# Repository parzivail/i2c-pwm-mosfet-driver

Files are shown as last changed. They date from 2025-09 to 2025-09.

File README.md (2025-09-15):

# I2C PWM MOSFET Driver

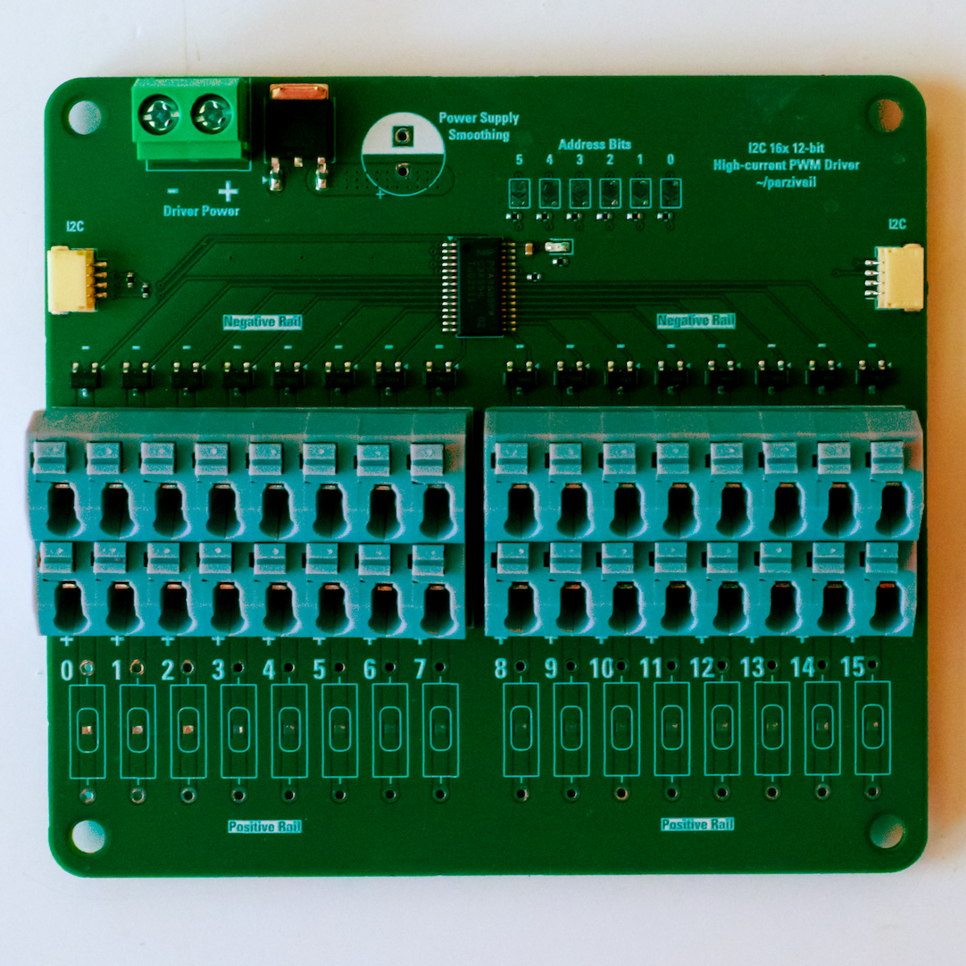
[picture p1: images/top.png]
An image of the circuit board


Buy this board [on Tindie](www.tindie.com/products/parzivail/i2c-pwm-mosfet-driver-mk-1/)!

This PWM driver board uses a PCA9685 controlled over I2C to drive up to 16 high-current loads with PWM via N-channeo MOSFETs. Perfect for 12V or 24V LED strips.

- PCA9685 PWM controller with 12-bit PWM resolution
- 3.3V and 5V compliant VCC and I2C
- Terminal block for driver power, isolated from chip power (provided over I2C)
- 16 independently-controlled outputs with up to 30V 3A per channel, driven by AO3400A N-channel MOSFETs
- Supports up to 5A total across all channels
- Reverse polarity protection via HXY AOD413A P-channel MOSFET up to 8A at 10V
- Two STEMMA QT/QUIIC-compatible I2C headers for daisy chaining
- 6-bit address select broken out on solder pads
- Spring-loaded terminal blocks for driver output
- Pads on each channel for optional current limiting resistors (bypassed by default with a solder jumper)
- Pads for optional power supply smoothing capacitor
- Red power LED
- 10K Pull-ups to VCC on SDA and SCL
- Compatible with Adafruit's PCA9685 libraries for Arduino and CircuitPython

## Changes from Mk1 to Mk2

- Removed polarity protection P-channel MOSFET
- Increased trace widths on each channel
- Converted an entire internal layer to a +V_LED power path

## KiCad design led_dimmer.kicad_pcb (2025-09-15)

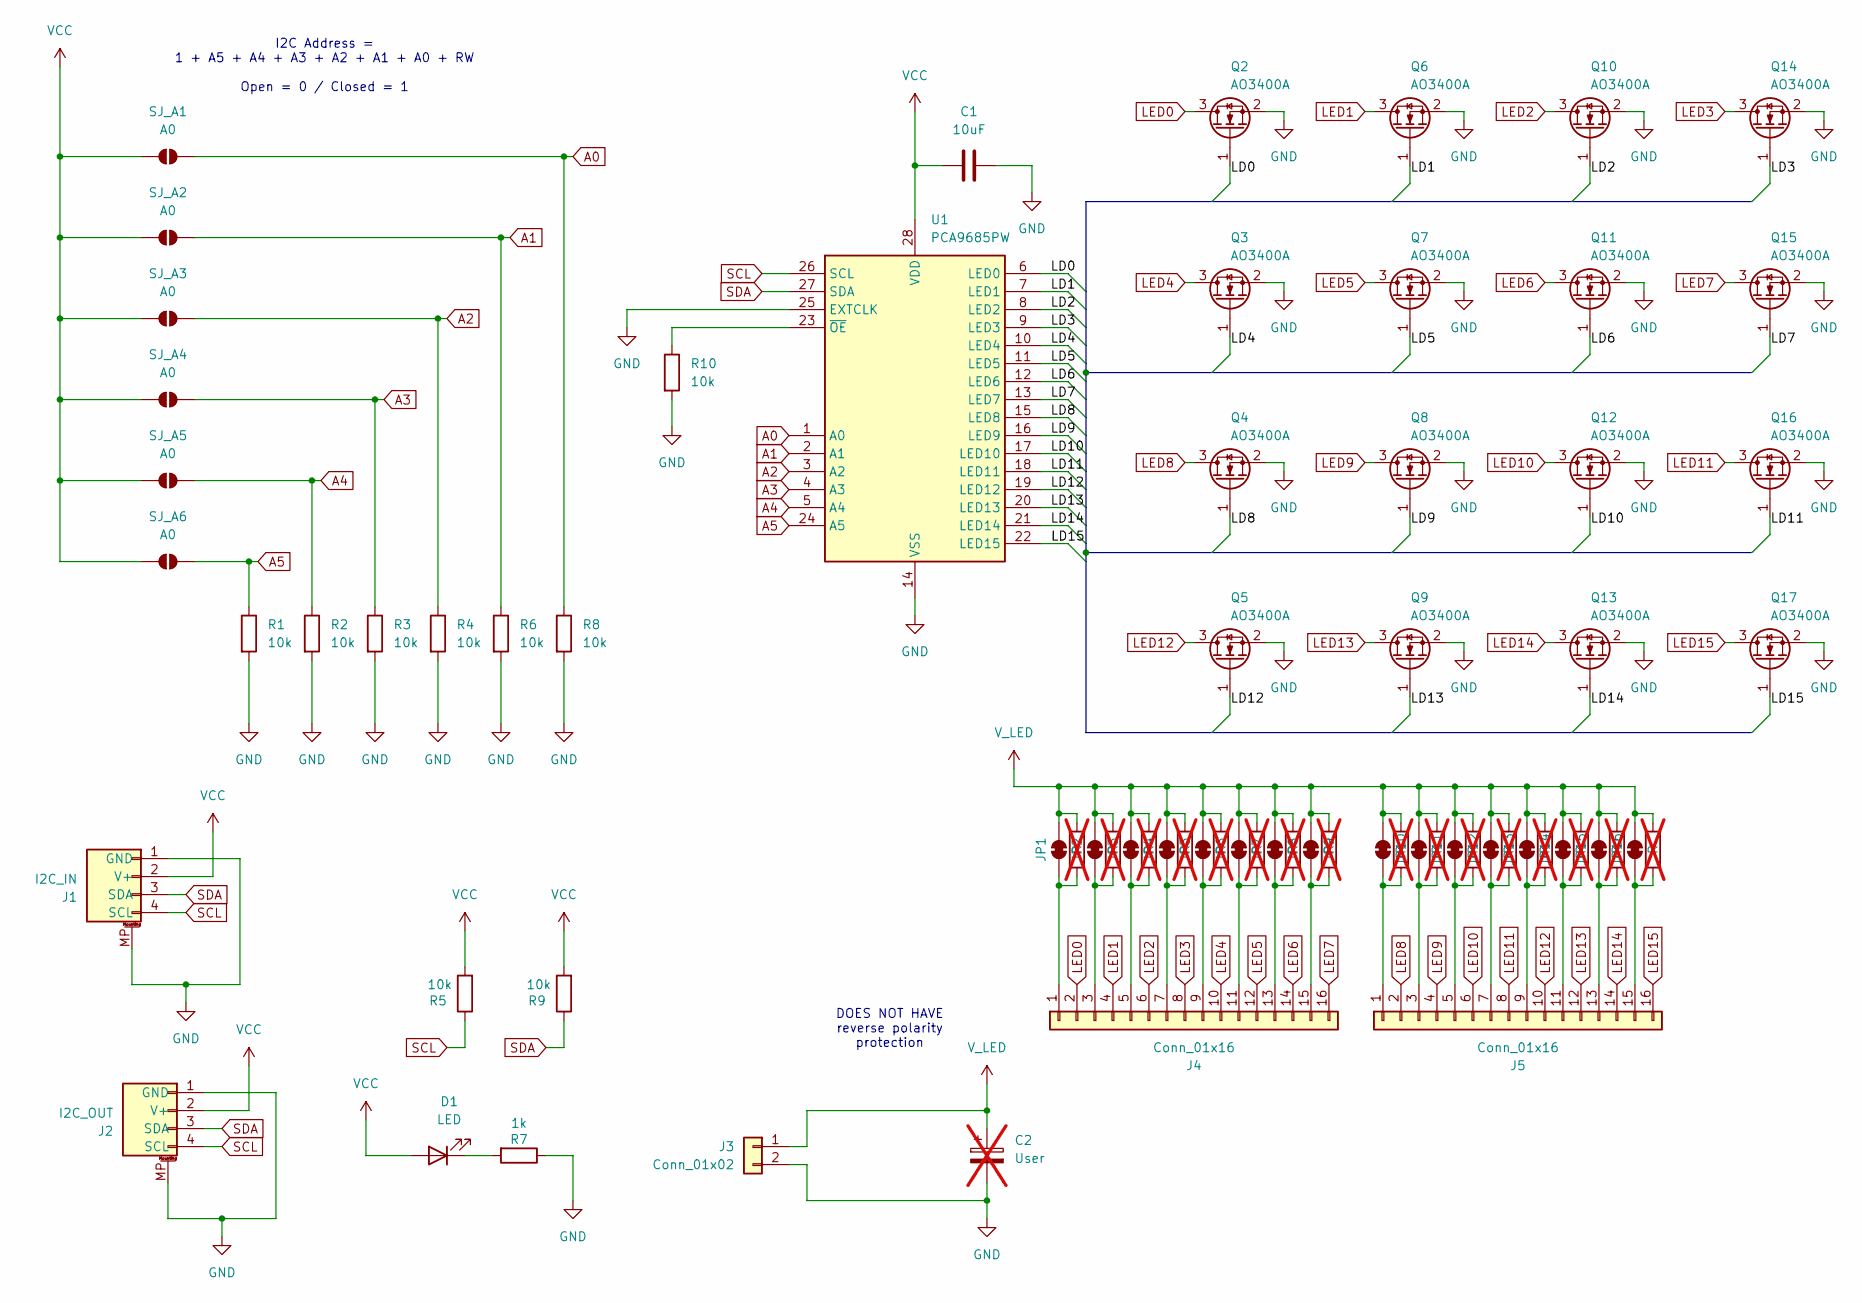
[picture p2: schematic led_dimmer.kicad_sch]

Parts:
C1: 10uF; C_0402_1005Metric; LCSC Part C15525
C2: User; CP_Radial_D8.0mm_P3.50mm; not fitted
D1: LED; LED_0603_1608Metric; LCSC Part C2286
J1: I2C_IN; JST_SH_SM04B-SRSS-TB_1x04-1MP_P1.00mm_Horizontal; LCSC Part C160404
J2: I2C_OUT; JST_SH_SM04B-SRSS-TB_1x04-1MP_P1.00mm_Horizontal; LCSC Part C160404
J3: Conn_01x02; TerminalBlock_Phoenix_MKDS-1,5-2_1x02_P5.00mm_Horizontal; LCSC Part C8404
J4, J5: Conn_01x16; CONN-TH_KF250T-5.0-2X8P; LCSC Part C976542
JP1, JP2, JP3, JP4, JP5, JP6, JP7, JP8, JP9, JP10, JP11, JP12, JP13, JP14, JP15, JP16: SolderJumper_2_Bridged; HighCurrentJumper
Q2, Q3, Q4, Q5, Q6, Q7, Q8, Q9, Q10, Q11, Q12, Q13, Q14, Q15, Q16, Q17: AO3400A; SOT-23; LCSC Part C20917
R1, R2, R3, R4, R5, R6, R8, R9, R10: 10k; R_0402_1005Metric; LCSC Part C25744
R7: 1k; R_0402_1005Metric; LCSC Part C11702
R11, R12, R13, R14, R15, R16, R17, R18, R19, R20, R21, R22, R23, R24, R25, R26: R; R_Axial_DIN0309_L9.0mm_D3.2mm_P12.70mm_Horizontal; not fitted
SJ_A1, SJ_A2, SJ_A3, SJ_A4, SJ_A5, SJ_A6: A0; SolderJumper-2_P1.3mm_Open_TrianglePad1.0x1.5mm
U1: PCA9685PW; TSSOP-28_4.4x9.7mm_P0.65mm; LCSC Part C2678753

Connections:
/LD0: Q2.1 (G), U1.6 (LED0)
/LD1: Q6.1 (G), U1.7 (LED1)
/LD2: Q10.1 (G), U1.8 (LED2)
/LD3: Q14.1 (G), U1.9 (LED3)
/LD4: Q3.1 (G), U1.10 (LED4)
/LD5: Q7.1 (G), U1.11 (LED5)
/LD6: Q11.1 (G), U1.12 (LED6)
/LD7: Q15.1 (G), U1.13 (LED7)
/LD8: Q4.1 (G), U1.15 (LED8)
/LD9: Q8.1 (G), U1.16 (LED9)
/LD10: Q12.1 (G), U1.17 (LED10)
/LD11: Q16.1 (G), U1.18 (LED11)
/LD12: Q5.1 (G), U1.19 (LED12)
/LD13: Q9.1 (G), U1.20 (LED13)
/LD14: Q13.1 (G), U1.21 (LED14)
/LD15: Q17.1 (G), U1.22 (LED15)
A0: R8.1, SJ_A1.2 (B), U1.1 (A0)
A1: R6.1, SJ_A2.2 (B), U1.2 (A1)
A2: R4.1, SJ_A3.2 (B), U1.3 (A2)
A3: R3.1, SJ_A4.2 (B), U1.4 (A3)
A4: R2.1, SJ_A5.2 (B), U1.5 (A4)
A5: R1.1, SJ_A6.2 (B), U1.24 (A5)
GND: C1.2, C2.2, J1.1 (GND), J1.MP, J2.1 (GND), J2.MP, J3.2, Q2.2 (S), Q3.2 (S), Q4.2 (S), Q5.2 (S), Q6.2 (S), Q7.2 (S), Q8.2 (S), Q9.2 (S), Q10.2 (S), Q11.2 (S), Q12.2 (S), Q13.2 (S), Q14.2 (S), Q15.2 (S), Q16.2 (S), Q17.2 (S), R1.2, R2.2, R3.2, R4.2, R6.2, R7.1, R8.2, R10.2, U1.14 (VSS), U1.25 (EXTCLK)
LED0: J4.2, Q2.3 (D)
LED1: J4.4, Q6.3 (D)
LED2: J4.6, Q10.3 (D)
LED3: J4.8, Q14.3 (D)
LED4: J4.10, Q3.3 (D)
LED5: J4.12, Q7.3 (D)
LED6: J4.14, Q11.3 (D)
LED7: J4.16, Q15.3 (D)
LED8: J5.2, Q4.3 (D)
LED9: J5.4, Q8.3 (D)
LED10: J5.6, Q12.3 (D)
LED11: J5.8, Q16.3 (D)
LED12: J5.10, Q5.3 (D)
LED13: J5.12, Q9.3 (D)
LED14: J5.14, Q13.3 (D)
LED15: J5.16, Q17.3 (D)
unnamed: D1.1 (K), R7.2
unnamed: J4.1, JP1.1 (A), R11.2
unnamed: J4.3, JP2.1 (A), R12.2
unnamed: J4.5, JP3.1 (A), R13.2
unnamed: J4.7, JP4.1 (A), R14.2
unnamed: J4.9, JP5.1 (A), R15.2
unnamed: J4.11, JP6.1 (A), R16.2
unnamed: J4.13, JP7.1 (A), R17.2
unnamed: J4.15, JP8.1 (A), R18.2
unnamed: J5.1, JP9.1 (A), R19.2
unnamed: J5.3, JP10.1 (A), R20.2
unnamed: J5.5, JP11.1 (A), R21.2
unnamed: J5.7, JP12.1 (A), R22.2
unnamed: J5.9, JP13.1 (A), R23.2
unnamed: J5.11, JP14.1 (A), R24.2
unnamed: J5.13, JP15.1 (A), R25.2
unnamed: J5.15, JP16.1 (A), R26.2
unnamed: R10.1, U1.23 (~OE)
SCL: J1.4 (SCL), J2.4 (SCL), R5.1, U1.26 (SCL)
SDA: J1.3 (SDA), J2.3 (SDA), R9.1, U1.27 (SDA)
VCC: C1.1, D1.2 (A), J1.2 (V+), J2.2 (V+), R5.2, R9.2, SJ_A1.1 (A), SJ_A2.1 (A), SJ_A3.1 (A), SJ_A4.1 (A), SJ_A5.1 (A), SJ_A6.1 (A), U1.28 (VDD)
V_LED: C2.1, J3.1, JP1.2 (B), JP2.2 (B), JP3.2 (B), JP4.2 (B), JP5.2 (B), JP6.2 (B), JP7.2 (B), JP8.2 (B), JP9.2 (B), JP10.2 (B), JP11.2 (B), JP12.2 (B), JP13.2 (B), JP14.2 (B), JP15.2 (B), JP16.2 (B), R11.1, R12.1, R13.1, R14.1, R15.1, R16.1, R17.1, R18.1, R19.1, R20.1, R21.1, R22.1, R23.1, R24.1, R25.1, R26.1

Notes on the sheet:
I2C Address = 1 + A5 + A4 + A3 + A2 + A1 + A0 + RW Open = 0 / Closed = 1
DOES NOT HAVE reverse polarity protection

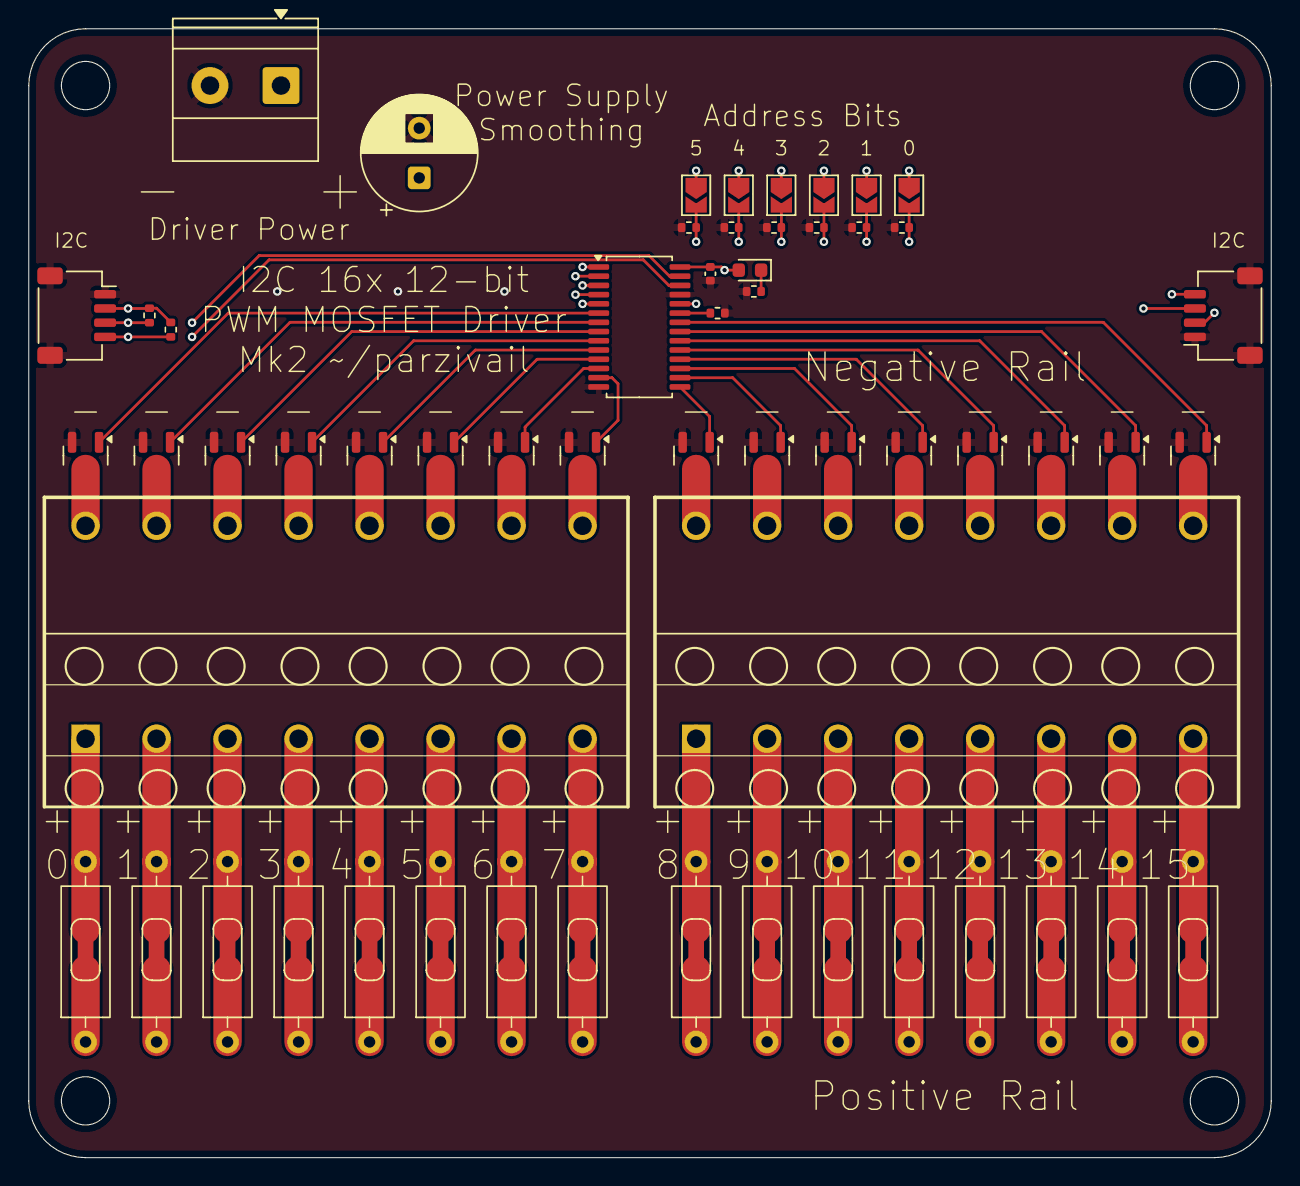
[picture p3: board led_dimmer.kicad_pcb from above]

Board: 4 copper layers, 87.5 x 79.5 mm, 73 parts (0 on the bottom side), 61 nets.
